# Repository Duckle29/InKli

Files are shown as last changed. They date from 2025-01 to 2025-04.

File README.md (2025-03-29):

# InKli

From the Danish "Indeklima" or "indoor climate", is an small sensor box, measuring CO2, temperature and relative humidity.

It displays this on an E-paper display, to allow you to keep an eye on the air in the room you're in.  
Additionally, as it is made with ESPHome, it can also easily connect to a Homeassistant instance, for further home automation and logging.




## History
Quite some time ago I built an air quality monitor, and played around with it. (https://blog.mikkel.cc/posts/airq/) It had PM10 sensors, CO2 sensors and BME680 for TVOC.

I've since had this running, and while it was fine, it was bulky, and I only ever really paid attention to the temperature, humidity and CO2 sensors.
The display I used on that box also had issues. Mainly with the backlight being a significant heat source, and an annoyance at night.

So now this is the replacement.
It has:
- ESP32
- 2.13" Waveshare E-paper display  (https://www.waveshare.com/2.13inch-e-paper.htm)
- IR remote demodulator
- 2 side-firing high-current IR LEDs 
- QWIIC port for future expansion / experimentation
- Single push button
- Touch-pad under screen (tested, works so~so, not great)
It also has a (hopefully) quite efficient 3V3 buck regulator to reduce self heating. (pretty good, seems around 2-3C self heating enclosed, mostly from the ESP itself )

At this point, I have the displays and the sensors. I'm getting most things working first, so I don't learn I've used a strapping pin when I have PCBs in hand and they don't cooperate.
I'm pretty happy with the simple display layout, and will see tomorrow how the graph turns out (set to 8h)

The IR blasters are there because one of these sensors will pull double duty, and act as an IR remote for a heat pump. 
On the rest of the PCBs these probably won't be populated.

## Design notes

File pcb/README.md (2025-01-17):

# SCD30 ESP32 backback

This is a small PCB combining an ESP32 WROOM module with an SCD30. It's intended to be USB powered, and has the option to mount a CH340C if you want on-board USB<>serial.

It's intended for use with ESPHome or similar.

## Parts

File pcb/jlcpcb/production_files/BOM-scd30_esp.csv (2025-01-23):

Comment | Designator | Footprint | LCSC | Quantity
120pF | C1 | C_0402_1005Metric | C106996 | 1
0.1uF | C20,C4 | C_0402_1005Metric | C1525 | 2
1uF | C10,C11,C12,C13,C14,C15,C16,C17,C5,C8,C9 | C_0603_1608Metric | C15849 | 11
USB_C_Receptacle_USB2.0 | J2 | USB_C_Receptacle_HRO_TYPE-C-31-M-12 | C165948 | 1
BSS138PS | Q3 | SOT-363_SC-70-6 | C193381 | 1
4.7uF | C3 | C_0805_2012Metric | C19666 | 1
68uF | L2 | L_1210_3225Metric | C223228 | 1
TPS62A01PDDCR | U1 | SOT-23-6 | C22445521 | 1
LED_Small | D7 | LED_0603_1608Metric | C2286 | 1
360k | R2 | R_0603_1608Metric | C23146 | 1
82k | R1 | R_0603_1608Metric | C23254 | 1
10k | R10,R13,R14,R17,R3,R7 | R_0603_1608Metric | C25804 | 6
1uH | L1 | L_1008_2520Metric | C435392 | 1
22uF | C2,C6,C7 | C_0805_2012Metric | C45783 | 3
Si1308EDL | Q1 | SOT-323_SC-70 | C469327 | 1
SW_SPST | SW1 | SW_SPST_EVQP2 | C512395 | 1
24P P0.5mm waveshare E-paper display | J3 | AMPHENOL_SFV24R-4STE1HLF | C5343283 | 1
NSR0530HT1G | D1,D2,D3,D4 | D_SOD-323 | C556393 | 4
2k2 | R12,R15,R4,R5,R8,R9 | R_0603_1608Metric | C6119849 | 6
ESP32-WROOM-E | U2 | ESP32-WROOM-32E | C701342 | 1
CH340C | U3 | SOIC-16_3.9x9.9mm_P1.27mm | C7464026 | 1
3R | R6 | R_0603_1608Metric |  | 1
TSOP38G36 | U4 | Vishay_MINICAST-3Pin |  | 1

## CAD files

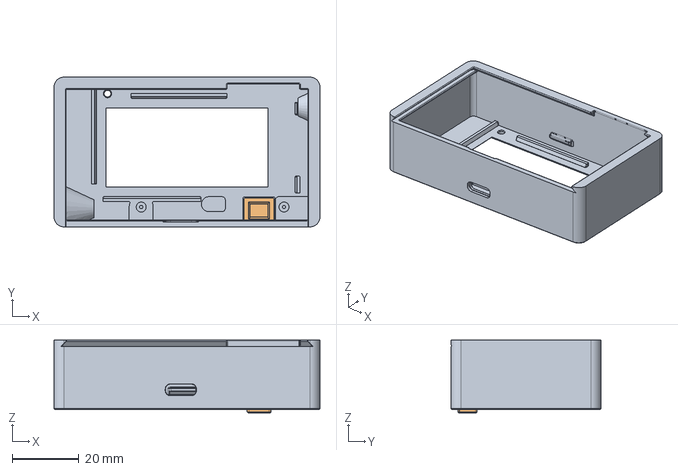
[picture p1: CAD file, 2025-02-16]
3D CAD/Case Assembly.step
79.7 x 44.9 x 21.9 mm

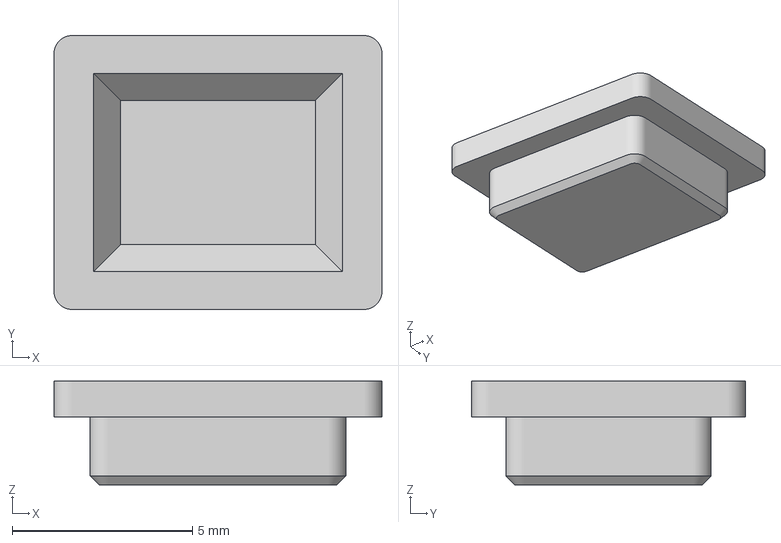
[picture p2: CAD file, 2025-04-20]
3D CAD/Button.3mf
9.10 x 7.60 x 2.88 mm

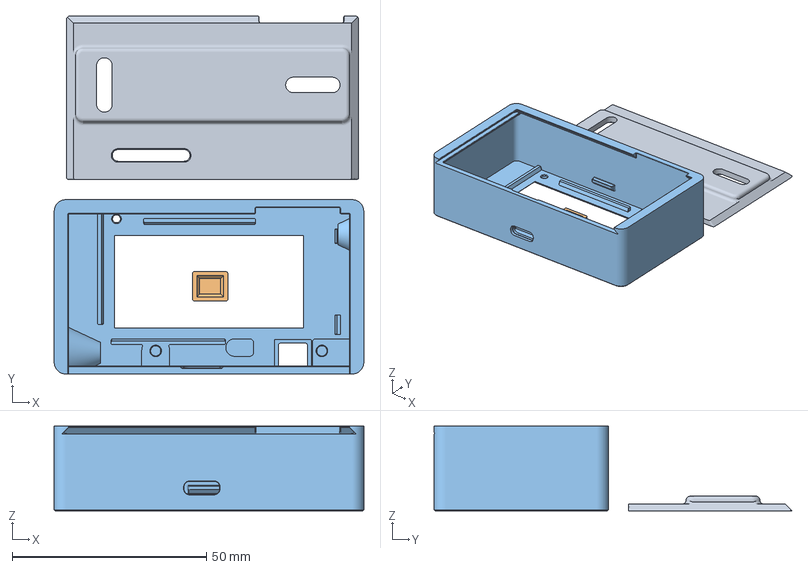
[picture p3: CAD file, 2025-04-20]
3D CAD/project.3mf
79.7 x 92.2 x 21.8 mm
Back_mounting plate
Button
case_with_modifiers

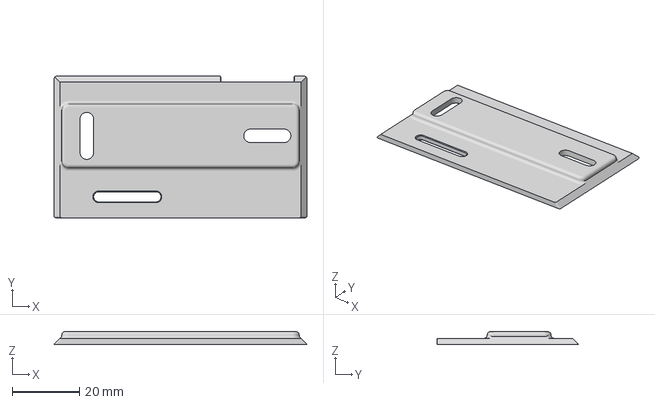
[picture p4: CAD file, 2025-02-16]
3D CAD/Back_mounting plate.3mf
75.2 x 42.2 x 3.80 mm

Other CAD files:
3D CAD/case_with_modifiers.3mf

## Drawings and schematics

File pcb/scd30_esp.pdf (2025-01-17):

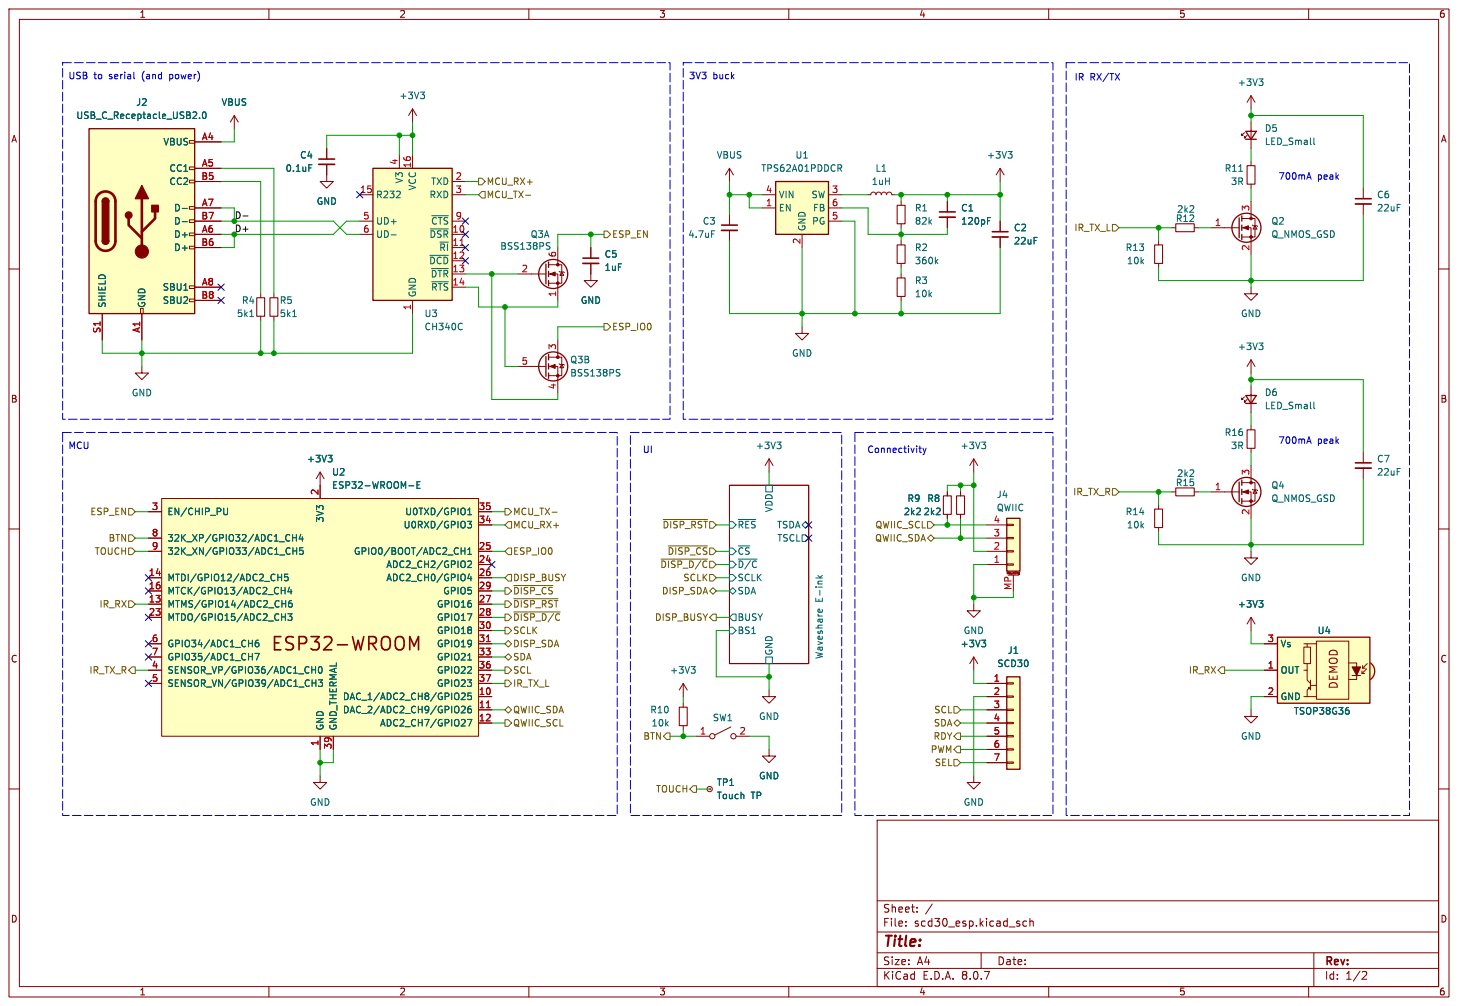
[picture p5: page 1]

2 SW 3 VIN 4 PG 5 FB 6 U1 TPS62A01PDDCR

1 ~{DSR} 10 ~{RI} 11 ~{DCD} 12 ~{DTR} 13 ~{RTS} 14 R232 15 VCC 16 TXD 2 RXD 3 V3

BUSY
Id: 1/2 Title: File: scd30_esp.kicad_sch Sheet: / GND

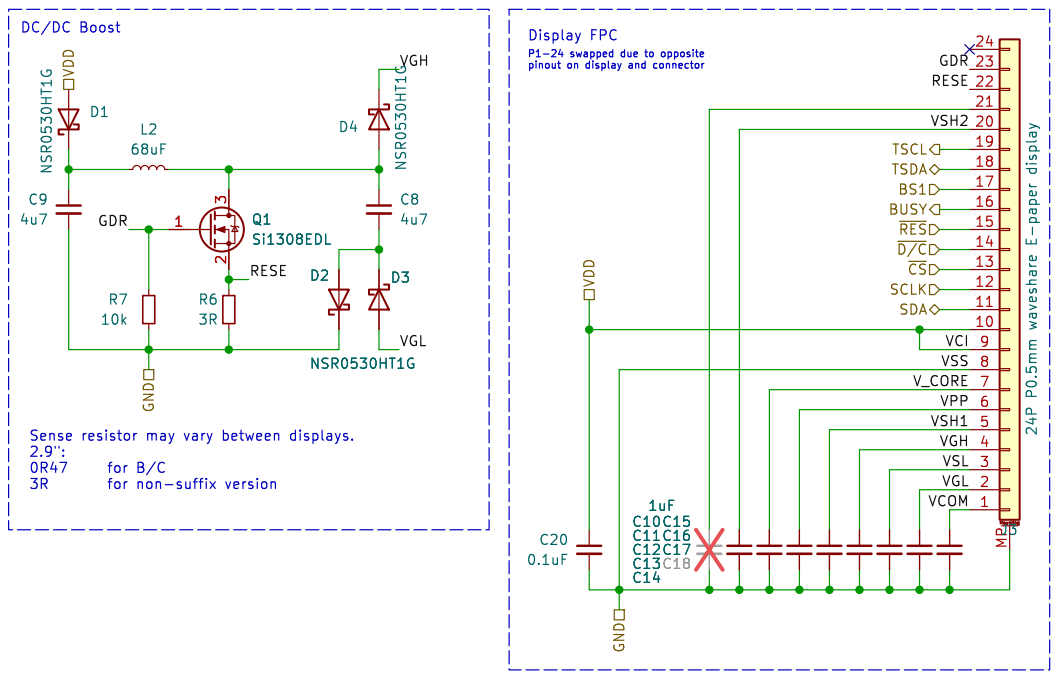
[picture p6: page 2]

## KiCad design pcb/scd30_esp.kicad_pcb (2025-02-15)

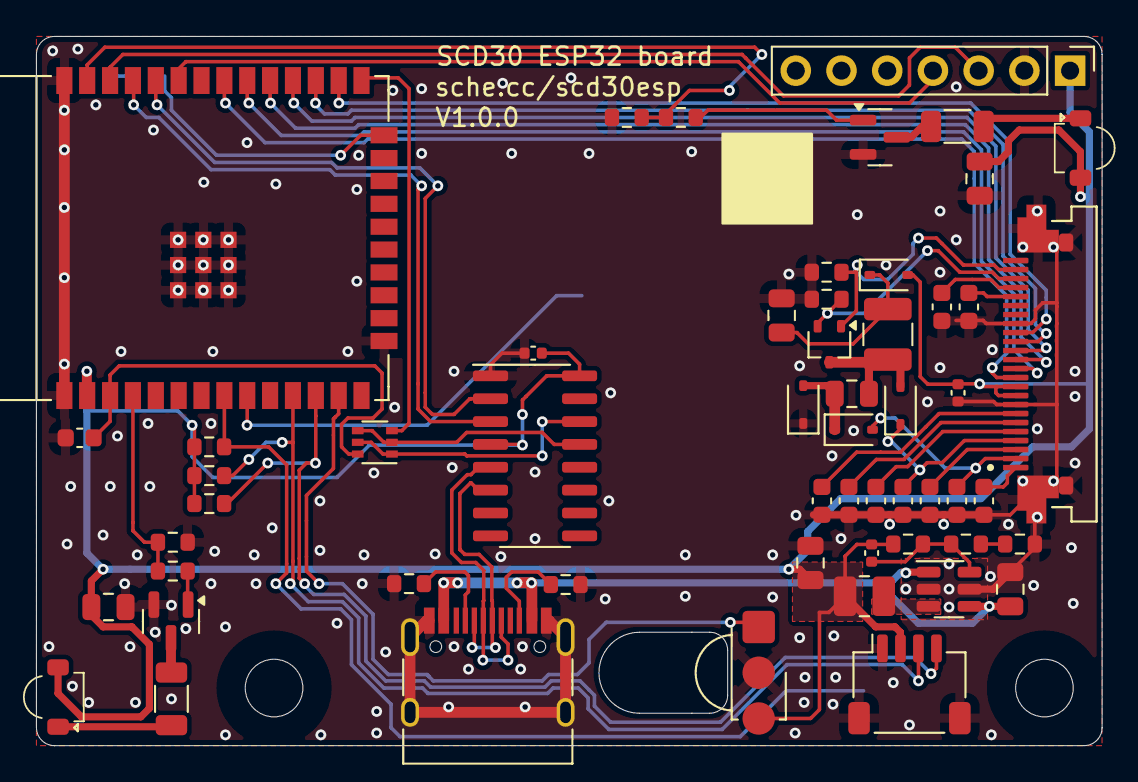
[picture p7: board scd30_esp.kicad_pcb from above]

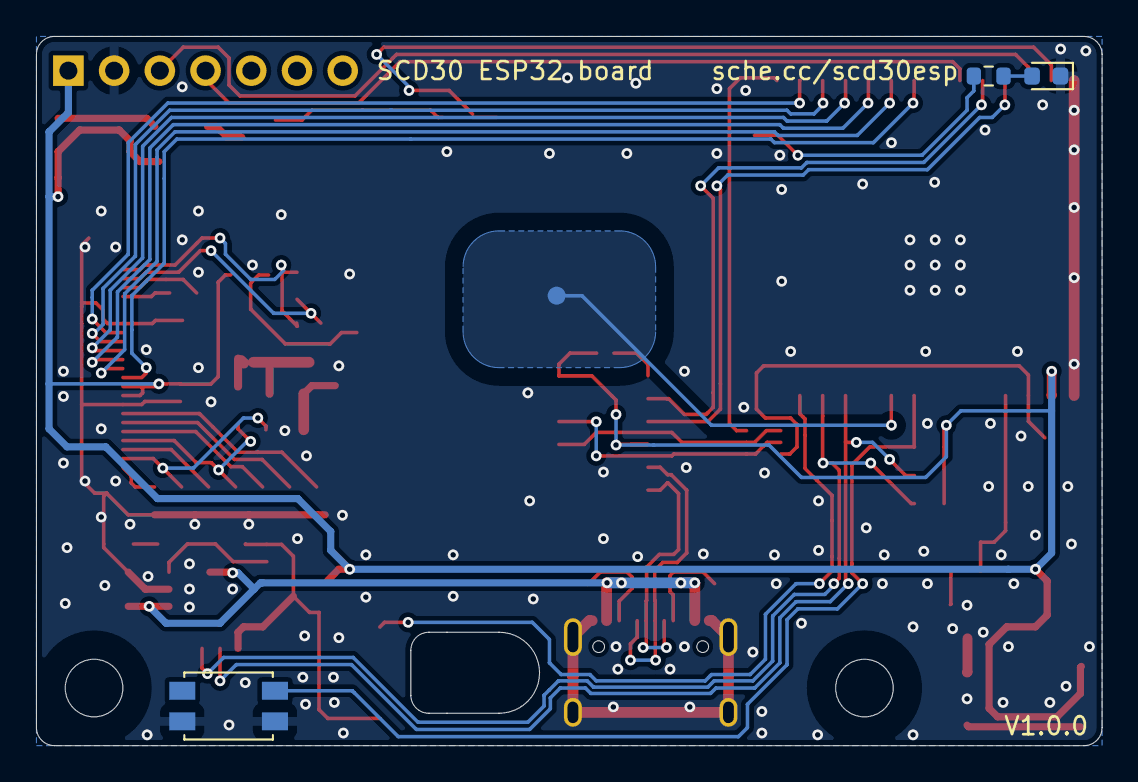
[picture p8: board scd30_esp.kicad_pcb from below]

Board: 2 copper layers, 59.2 x 39.4 mm, 59 parts (4 on the bottom side), 53 nets.

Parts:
C1: 120pF; C_0402_1005Metric
C2, C6, C7: 22uF; C_0805_2012Metric
C3: 4.7uF; C_0805_2012Metric
C4, C20: 0.1uF; C_0402_1005Metric
C5, C10, C11, C12, C13, C14, C15, C16, C17, C18: 1uF; C_0603_1608Metric
C8, C9: 4u7; C_0805_2012Metric
D1, D2, D3, D4: NSR0530HT1G; D_SOD-323
D5, D6: LED_Small; LED_Vishay_VSMB2943SL
D7: LED_Small; LED_0603_1608Metric
J1: SCD30; PinHeader_1x07_P2.54mm_Vertical
J2: USB_C_Receptacle_USB2.0; USB_C_Receptacle_HRO_TYPE-C-31-M-12
J3: 24P P0.5mm waveshare E-paper display; AMPHENOL_SFV24R-4STE1HLF
J4: QWIIC; JST_SH_SM04B-SRSS-TB_1x04-1MP_P1.00mm_Horizontal
L1: 1uH; L_1008_2520Metric
L2: 68uF; L_1210_3225Metric
Q1: Si1308EDL; SOT-323_SC-70
Q2, Q4: Q_NMOS_GSD; SOT-23
Q3: BSS138PS; SOT-363_SC-70-6
R1: 82k; R_0603_1608Metric
R2: 360k; R_0603_1608Metric
R3, R7, R10, R13, R14: 10k; R_0603_1608Metric
R4, R5: 5k1; R_0603_1608Metric
R6: 3R; R_0603_1608Metric
R8, R9, R12, R15: 2k2; R_0603_1608Metric
R11, R16: 3R; R_1206_3216Metric
R17: 1k; R_0603_1608Metric
SW1: SW_SPST; SW_SPST_EVQP2
TP1: Touch TP; TestPoint_Pad_D1.0mm
U1: TPS62A01PDDCR; SOT-23-6
U2: ESP32-WROOM-E; ESP32-WROOM-32E
U3: CH340C; SOIC-16_3.9x9.9mm_P1.27mm
U4: TSOP38G36; Vishay_MINICAST-3Pin

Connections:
+3V3: C1.1, C2.1, C4.1, C6.1, C7.1, C20.1, D1.2 (A), D5.2 (A), D6.2 (A), J1.1, J3.9, J3.10, J4.2, L1.2, R1.1, R8.1, R9.1, R10.1, U2.2 (3V3), U3.4 (V3), U3.16 (VCC), U4.3 (Vs)
/BTN: R10.2, SW1.1 (A), U2.8 (32K_XP/GPIO32/ADC1_CH4)
/D+: J2.A6 (D+), J2.B6 (D+), U3.5 (UD+)
/D-: J2.A7 (D-), J2.B7 (D-), U3.6 (UD-)
/DISP_BUSY: J3.16, U2.26 (ADC2_CH0/GPIO4)
/DISP_SDA: J3.11, U2.31 (GPIO19)
/ESP_EN: C5.1, Q3.6 (D), U2.3 (EN/CHIP_PU)
/ESP_IO0: Q3.3 (D), U2.25 (GPIO0/BOOT/ADC2_CH1)
/IR_RX: U2.13 (MTMS/GPIO14/ADC2_CH6), U4.1 (OUT)
/IR_TX_L: R12.1, R13.1, U2.37 (GPIO23)
/IR_TX_R: R14.1, R15.1, U2.4 (SENSOR_VP/GPIO36/ADC1_CH0)
/MCU_RX+: U2.34 (U0RXD/GPIO3), U3.2 (TXD)
/MCU_TX-: U2.35 (U0TXD/GPIO1), U3.3 (RXD)
/QWIIC_SCL: J4.4, R9.2, U2.12 (ADC2_CH7/GPIO27)
/QWIIC_SDA: J4.3, R8.2, U2.11 (DAC_2/ADC2_CH9/GPIO26)
/SCL: J1.3, U2.36 (GPIO22)
/SCLK: J3.12, U2.30 (GPIO18)
/SDA: J1.4, U2.33 (GPIO21)
/TOUCH: TP1.1, U2.9 (32K_XN/GPIO33/ADC1_CH5)
/Waveshare E-ink/GDR: J3.23, Q1.1 (G), R7.1
/Waveshare E-ink/RESE: J3.22, Q1.2 (S), R6.1
/Waveshare E-ink/VCOM: C10.1, J3.1
/Waveshare E-ink/VGH: C13.1, D4.1 (K), J3.4
/Waveshare E-ink/VGL: C11.1, D3.2 (A), J3.2
/Waveshare E-ink/VPP: C15.1, J3.6
/Waveshare E-ink/VSH1: C14.1, J3.5
/Waveshare E-ink/VSH2: C17.1, J3.20
/Waveshare E-ink/VSL: C12.1, J3.3
/Waveshare E-ink/V_CORE: C16.1, J3.7
/status_led: R17.2, U2.24 (ADC2_CH2/GPIO2)
/~DISP_CS: J3.13, U2.29 (GPIO5)
/~DISP_D/C: J3.14, U2.28 (GPIO17)
/~DISP_RST: J3.15, U2.27 (GPIO16)
GND: C2.2, C3.2, C4.2, C5.2, C6.2, C7.2, C9.2, C10.2, C11.2, C12.2, C13.2, C14.2, C15.2, C16.2, C17.2, C18.2, C20.2, D2.1 (K), D7.1 (K), J1.2, J2.A1 (GND), J2.A12 (GND), J2.B1 (GND), J2.B12 (GND), J2.S1 (SHIELD), J3.8, J3.17, J3.MP (MountPin), J4.1, J4.MP (MountPin), Q2.2 (S), Q4.2 (S), R3.2, R4.2, R5.2, R6.2, R7.2, R13.2, R14.2, SW1.2 (B), U1.2 (GND), U1.5 (PG), U2.1 (GND), U2.15 (GND), U2.38 (GND), U2.39 (GND_THERMAL), U3.1 (GND), U4.2 (GND)
unnamed: C9.1, D1.1 (K), L2.1
unnamed: C8.2, D2.2 (A), D3.1 (K)
unnamed: C8.1, D4.2 (A), L2.2, Q1.3 (D)
unnamed: D5.1 (K), R11.1
unnamed: D6.1 (K), R16.1
unnamed: D7.2 (A), R17.1
unnamed: J2.A5 (CC1), R5.1
unnamed: J2.B5 (CC2), R4.1
unnamed: C18.1, J3.21
unnamed: Q2.3 (D), R11.2
unnamed: Q2.1 (G), R12.2
unnamed: Q3.2 (G), Q3.4 (S), U3.13 (~DTR)
unnamed: Q3.1 (S), Q3.5 (G), U3.14 (~RTS)
unnamed: Q4.3 (D), R16.2
unnamed: Q4.1 (G), R15.2
unnamed: R2.2, R3.1
unnamed: C1.2, R1.2, R2.1, U1.6 (FB)
unnamed: L1.1, U1.3 (SW)
VBUS: C3.1, J2.A4 (VBUS), J2.A9 (VBUS), J2.B4 (VBUS), J2.B9 (VBUS), U1.1 (EN), U1.4 (VIN)

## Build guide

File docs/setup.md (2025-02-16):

# InKli first setup

Hi! So you want to connect your InKli to your network, to get more out of it, great! :D

Connecting this to your netowrk only really gains you any features if you also plan to connect it to a homeassistant instance,
or an MQTT server.  
If you don't plan to do so, feel free to enjoy it standalone.  
The device should exit the config screen after 1 minute of power
on time.

## Connect to wifi
You have three options to connect your InKli to your wifi:

1. **ImprovBLE** Set up the wifi from a computer over Bluetooth. Supports Chrome or Edge browsers
1. **ImprovSerial** Set up wifi from a computer over USB. Supports Chrome or Edge browswers
1. **WiFi Access point** Set up through the devices backup wifi hotspot. Supports anything with wifi

## 1&2: Improv BLE and Improv Serial 
To connect the device using either improv solutions, visit: https://www.improv-wifi.com/ with a supported browser.
If using Improv Serial, make sure to connect the device to your computer with a USB cable.

## 3: Through the device backup access point
This method is done easiest through a phone, but can be done on anything with wifi.

Go to your wifi settings, and connect to the InKli Config hotspot. It'll have a 6 character address after it's name too.
To get the password for the network, push the front button to go to the AP info screen.

Once connected, you should be prompted to "log in" to the network. If you're not prompted, got to your browser and navigate to http://192.168.4.1

On this page, you can then select your wifi, and sign in to it.

That's it! :) Your InKli should now be on your network.

## Homeassistant
If you're running a homeassistant setup on the network with your InKli, you should now be able to find your InKli there.

Further HA instructions to follow

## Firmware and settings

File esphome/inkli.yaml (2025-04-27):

substitutions:
  name: "inkli"
  friendly_name: "InKli"
  version: "v0.1.1"

# Enable logging
logger:
  level: INFO

# esp32_touch:
#   setup_mode: False

binary_sensor:
  - platform: gpio
    id: btn
    pin:
      number: GPIO32
      inverted: True
      #allow_other_uses: True
      mode:
        input: True
        pullup: True
    on_click:
      - min_length: 50ms
        max_length: 350ms
        then:
          - display.page.show_next: disp
          - component.update: disp

      - min_length: 1s
        max_length: 5s
        then:
          - if:
              condition:
                or:
                  - display.is_displaying_page: ap_info
                  - display.is_displaying_page: page_setup
              then:
                - display.page.show: page_co2_graph
              else:
                - display.page.show: ap_info
          - if:
              condition:
                and:
                  - not:
                    - wifi.enabled:
                  - display.is_displaying_page: ap_info
              then:
                - wifi.enable:
                # TODO: non-blocking delay - delay: 5min
                - if:
                    condition:
                      wifi.connected:
                    else:
                      wifi.disable:


      - min_length: 5s
        max_length: 60s
        then:
          - display.page.show: page_updating
          - component.update: disp
          - delay: 1s
          - ota.http_request.flash:
              md5_url: https://otaserv.mikkel.cc/inkli/inkli-esp32.ota.bin.md5
              url: https://otaserv.mikkel.cc/inkli/inkli-esp32.ota.bin
          - display.page.show: page_update_failed
          - component.update: disp
          - delay: 10s
          - display.page.show: page_co2_graph
          - component.update: disp

  # - platform: esp32_touch
  #   pin: GPIO33
  #   threshold: 1040
  #   id: touch_test
  #   filters:
  #     - delayed_off: 
  #         milliseconds: 500
  #   on_press: 
  #     then:
  #       - display.page.show_next: disp

sensor:
  - platform: uptime
    id: uptime_sens
    on_value_range:
      - above: 60.0
        then:
          - if:
              condition:
                - display.is_displaying_page: page_setup
              then:
                - display.page.show: page_co2_graph

  - platform: scd30
    i2c_id: i2c_scd30
    address: 0x61
    update_interval: 30s
    temperature_offset: 3
    co2:
      id: scd30_co2
      name: "co2"
      accuracy_decimals: 0
      internal: False
      on_value_range:
        - above: 2000
          then:
            - output.set_level:
                id: led_status
                level: 50%
            - output.turn_on: led_status
        - below: 2000
          then:
            - output.turn_off: led_status

    temperature:
      id: scd30_t
      name: "temperature"
      accuracy_decimals: 2
      internal: False
    humidity:
      name: "humidity"
      id: scd30_rh
      accuracy_decimals: 2
      internal: False
  
  - platform: wifi_signal
    id: wifi_sig
    update_interval: 60s
    filters:
      - lambda: return min(max(2 * (x+100.0), 0.0), 100.0);
  
text_sensor:
  - platform: wifi_info
    ip_address: 
      id: wifi_ip_addr
    ssid: 
      id: wifi_ssid
    mac_address: 
      id: wifi_mac

# external_components:
#   - source: github://pr#8112
#     components:
#       - graph
#     #refresh: 1s

# Example on how to implement a UI section in HA for manual calibration.
# Note: Please enter first a CO2 value before pressing the button.
button:
  - platform: factory_reset
    name: Restart with Factory Default Settings
    
  - platform: template
    name: "CO2 sensor force manual calibration"
    entity_category: "config"
    on_press:
      then:
        - scd30.force_recalibration_with_reference:
            value: !lambda 'return id(co2_cal).state;'

number:
  - platform: template
    name: "CO2 manual calibration value"
    optimistic: true
    min_value: 350
    max_value: 4500
    initial_value: 400
    step: 1
    id: co2_cal
    icon: "mdi:molecule-co2"
    entity_category: "config"

output:
  - platform: ledc
    id: led_status
    pin: GPIO2
    frequency: 19531
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

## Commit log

2024-12-28 Saved schematic
    [scd30_esp.kicad_sch]
2025-01-01 Initial schematic
    [CPL-scd30_esp.csv, scd30_esp-CuBottom.gbr, scd30_esp-CuTop.gbr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]
2025-01-03 Initial layout
    [scd30_esp.kicad_pcb, waveshare_eink.kicad_sch]
2025-01-17 moved files to sub-folders
    [scd30_esp.kicad_pcb, scd30_esp.kicad_sch, waveshare_eink.kicad_sch]
2025-01-23 Added alternate footprint for XFCN FPC connector
    [scd30_esp.kicad_pcb]
2025-01-23 nudged components, added version text
    [scd30_esp.kicad_pcb]
2025-01-23 Added JLCPCB production files
    [BOM-scd30_esp.csv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]
2025-02-15 Initial esphome yaml, and 3D CAD
    [Back_mounting plate.3mf, Button.3mf, case_with_modifiers.3mf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]
2025-02-15 Added factory reset
    [scd30_esp.kicad_sch]
2025-02-15 Dedupe button
2025-02-16 Updated hosing design. Name change to InKli
    [Back_mounting plate.3mf, Button.3mf, Case Assembly.step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]
2025-02-16 Added setup instructions
    [case_with_modifiers.3mf, project.3mf]
2025-02-16 Update case clearances slightly
    [Case Assembly.step, case_with_modifiers.3mf, project.3mf]
2025-02-19 Set min ESPHome version to 2025.02.00
    [project.3mf]
2025-04-20 Updated CAD files for better printability
    [Button.3mf, case_with_modifiers.3mf, project.3mf]
2025-04-21 fix string, depend on upload job
    [inkli.yaml]
